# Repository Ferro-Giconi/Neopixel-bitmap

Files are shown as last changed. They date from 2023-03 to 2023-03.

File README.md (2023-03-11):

# Neopixel-bitmap
A Raspberry Pi Pico program to display images on a Neopixel RGB LED array.

Instructions:

1. Use BitmapToArray.py on your computer to convert bitmaps into arrays. Save those arrays to BitmapData.py following or replacing the existing examples.

2. Make sure your Pico/2040 device has MicroPython on it.

3. Add custom code for animations to the animations section in main.py

4. Make sure to set number_of_animations to the number of animations so it knows how many to loop through when pushing the buttons

5. Flash main.py and BitmapData.py to your RPi Pico/2040 device.

(Images or schematics or something to show how to connect all the hardware together will come later)

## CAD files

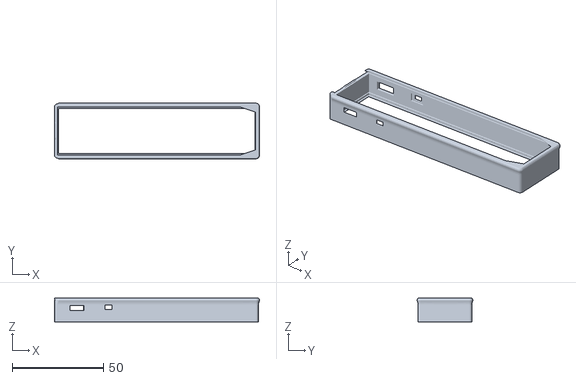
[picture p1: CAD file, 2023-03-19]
STL/main body with front insert.stl
112.4 x 30.5 x 13.1

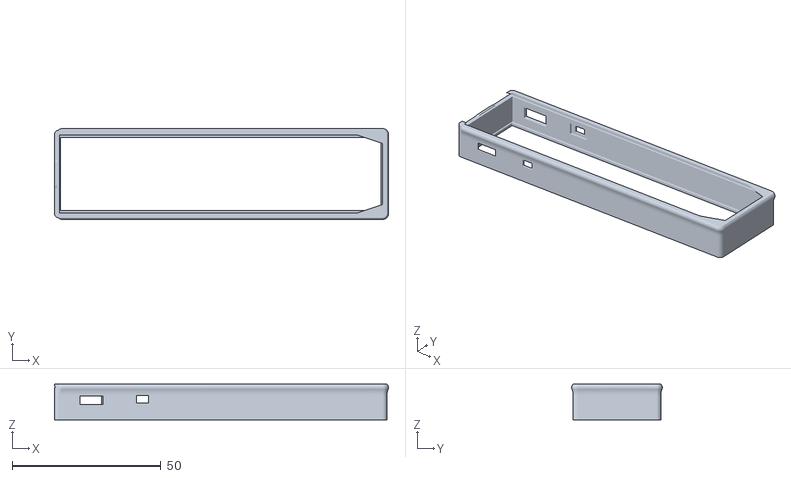
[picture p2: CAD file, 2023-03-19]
STL/main body with no front.stl
112.4 x 30.5 x 12.1

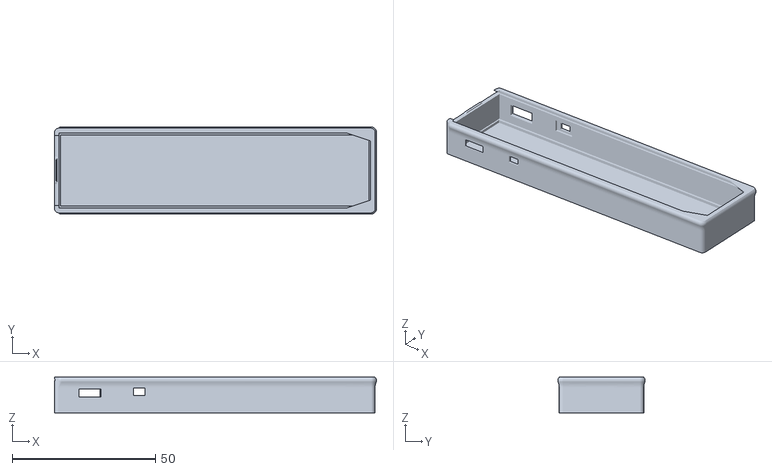
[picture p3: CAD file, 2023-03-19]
STL/main body with integrated front.stl
112.4 x 30.5 x 12.5

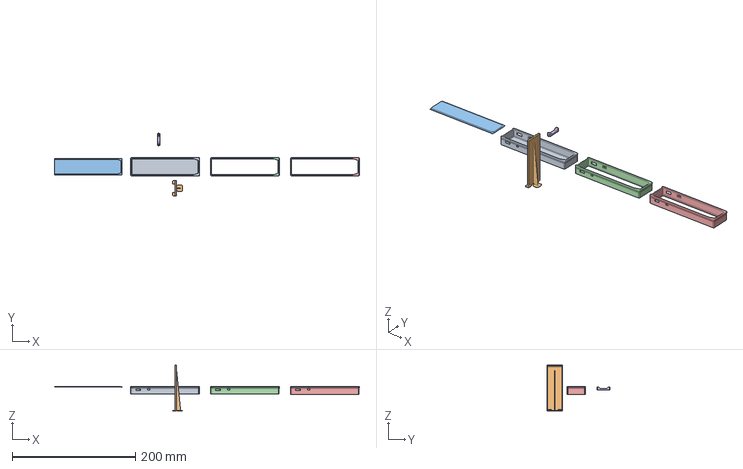
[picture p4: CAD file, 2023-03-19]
STL/All parts.step
495.9 x 102.6 x 74.7 mm

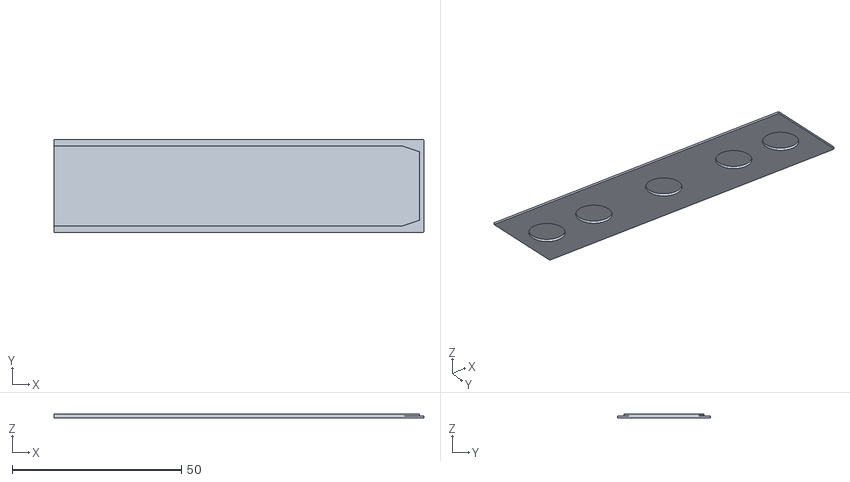
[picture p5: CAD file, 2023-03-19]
STL/back.stl
109.4 x 27.4 x 1.20

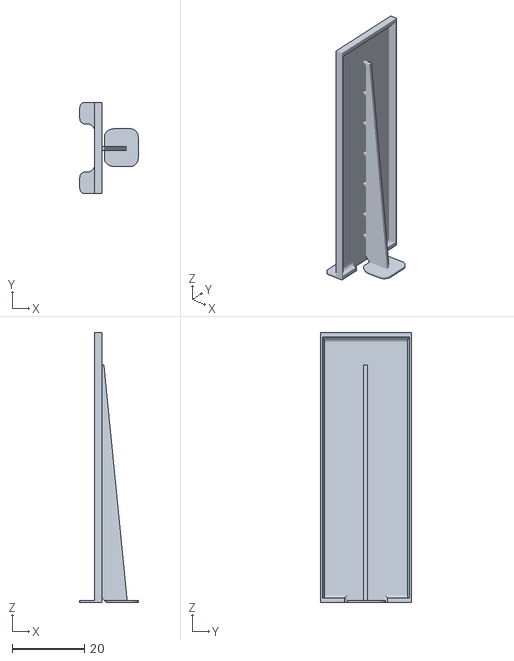
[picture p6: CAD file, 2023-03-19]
STL/battery tray.stl
16.2 x 25.3 x 74.7

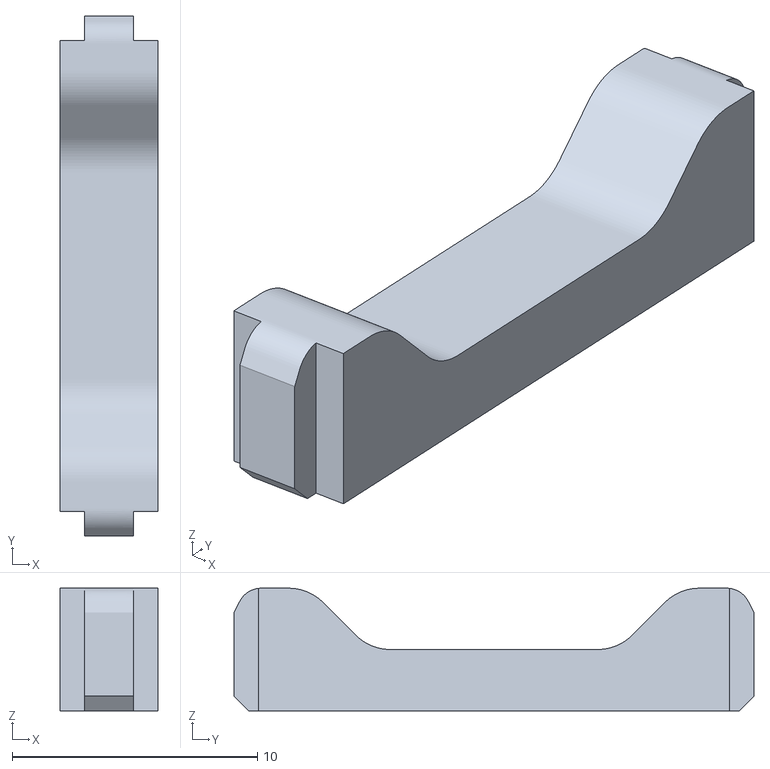
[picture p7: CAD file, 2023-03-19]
STL/button brace.stl
4.00 x 21.2 x 5.00

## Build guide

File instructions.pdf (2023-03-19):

# Required parts page 1

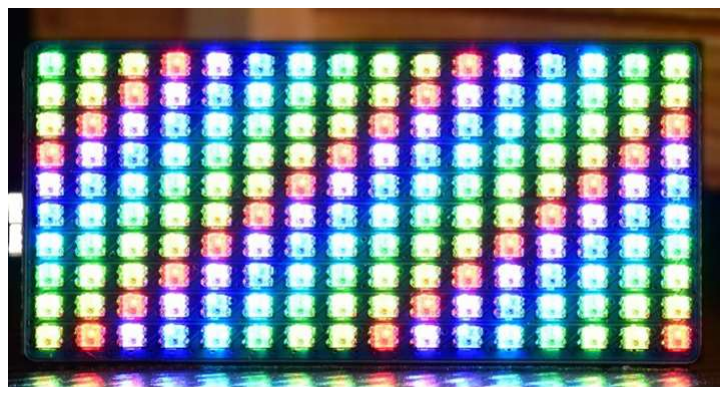
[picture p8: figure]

2 X Waveshare RGB Full-color LED Matrix Panel for Raspberry Pi Pico, 16×10 Grid
https://www.waveshare.com/pico-rgb-led.htmhttps://www.amazon.com/dp/B09CHFXLHV

### 1 X Pimironi Tiny 2040 8MB WITHOUT HEADER PINS

https://shop.pimoroni.com/products/tiny-2040?variant=39560012234835

### 1 X Pimironi LiPo SHIM for Pico

https://shop.pimoroni.com/products/pico-lipo-shim?variant=32369543086163

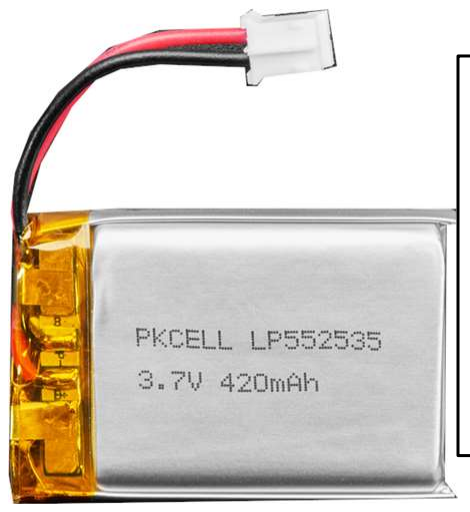
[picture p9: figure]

### 2 X LiPo battery 552535

https://www.adafruit.com/product/4236

(this was the best way I found to fit as much battery as possible into the space available. A single battery that fits the space would have been ideal to increase the mAh capacity but oh well.)

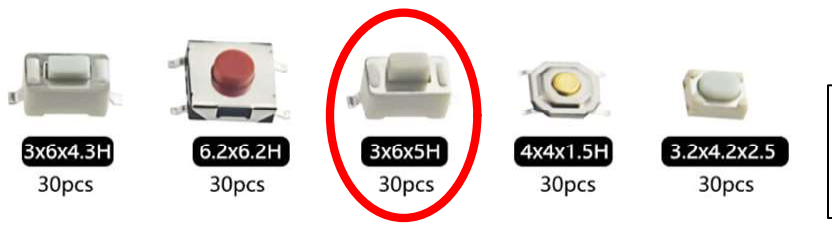
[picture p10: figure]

### 2 X 3x6x5H tactile switch

https://www.amazon.com/dp/B07GNZM4YJ

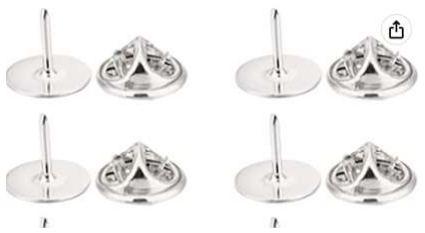
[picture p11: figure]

Pin backs, at least a 2 pack. Metal backings recommended, as the plastic ones can sometimes fall off. https://www.amazon.com/dp/B09WQHPBZW/

# Required parts page 2

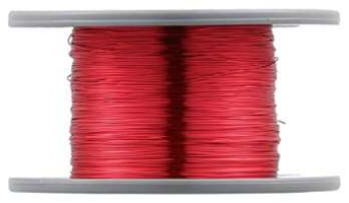
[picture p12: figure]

### 26 AWG enameled copper wire to carry up to 1A which can happen

with two Waveshare 16x10 arrays displaying all white.

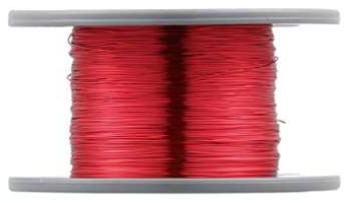
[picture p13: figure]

### 30 AWG enameled copper wire (optional)

To save space by using thinner wire on any wires that don’t need to carry current to and from the 16x10 LED arrays.

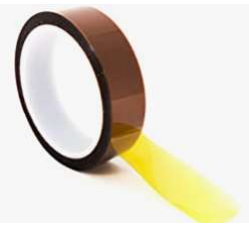
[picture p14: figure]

Polyimide Film with Silicone Adhesive. Also known as the name brand Kapton tape. This is needed to insulate stuff because there isn’t space for the thickness of normal electrical tape. I used 0.5" wide, but any width will work.

Other tools you will need: Soldering iron
Hot glue gun
Craft “xacto” knife.
3D printer

PicoShim: Remove the battery header.
Desolder all remaining metal bits. | Tiny 2040: Remove the buttons
| (The LED can stay)

Batteries: Remove the plug (but not the wires) from both batteries. Strip the ends of the wires, leaving about 1/8th of an inch of exposed wire. Put tape over the positive or negative so you don’t accidentally short something.

Required steps before assembly (but after testing on a breadboard)

Waveshare 16x10 LED array: Remove all three headers from the LED arrays.

Tip: use side cutters or another small cutting tool to break away the plastic. Once all the plastic is removed, it will be easier to desolder the remaining bits of metal.

Tip: use side cutters or another small cutting tool to break away the plastic. Once you get the switches to be as thin as the LED, you do not need to continue any further but if you do, be very careful when desoldering the buttons as it is very easy to rip off solder pads.

Tips:
Large headers: Wiggle back and forth gently a lot of times. They will eventually break off from metal fatigue. Desolder the individual pins now that they aren’t held together with a piece of plastic.

Small header: heat up the 5V pin solder first. Once it is melted, use side cutters to cut the plastic to remove the 5V pin. Do the same for the rest of the pins.

# Explanation of solder points

Tiny 2040: No special notes. PicoShim: Charge and Discharge should be bridged together.

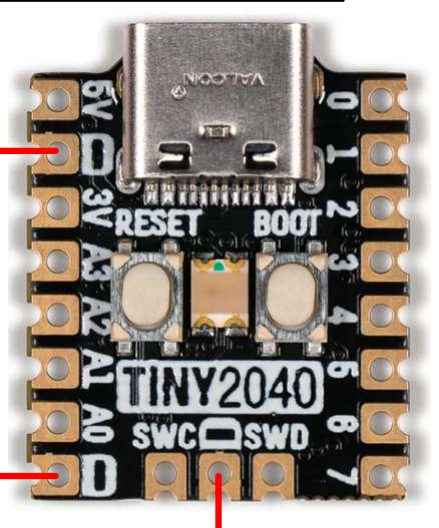
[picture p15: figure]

Charge

Discharge

Ground

Ground

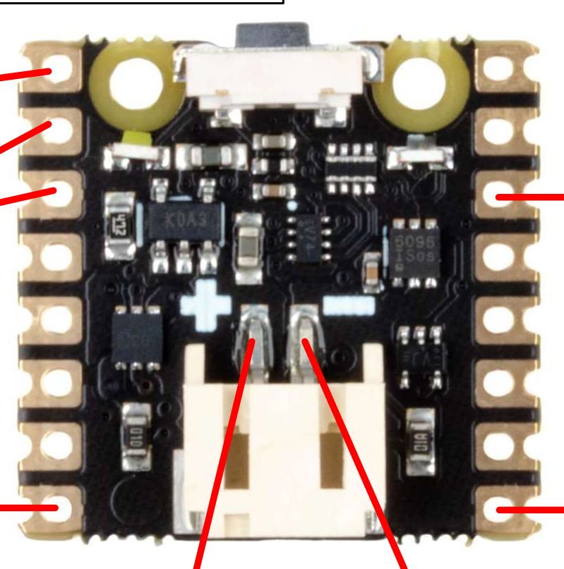
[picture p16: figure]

BAT + | BAT -

Waveshare 16x10 LED array: VBUS and 5V are the same. GP6 can be used as an alternative to DIN.

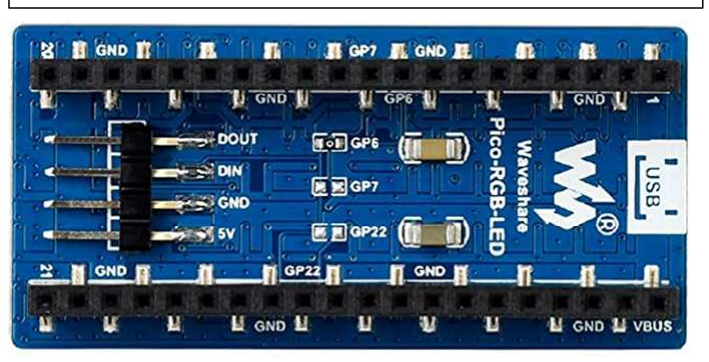
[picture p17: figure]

# Schematic

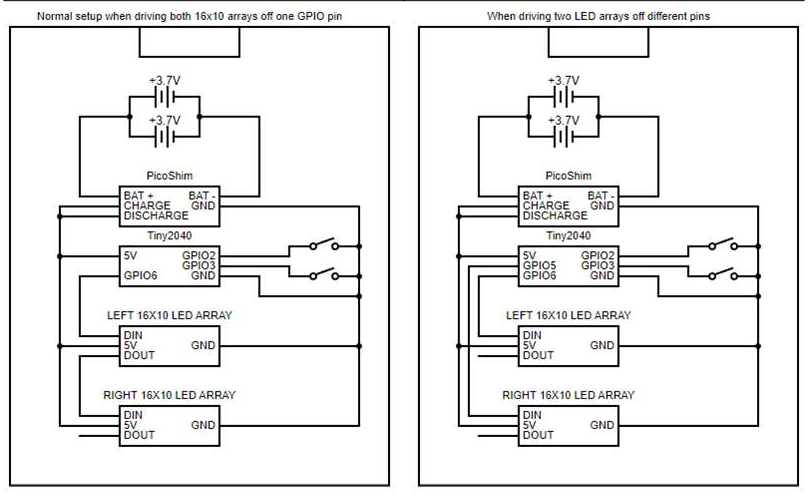
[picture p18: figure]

https://crcit.net/c/523c296d15b04a64b24df0ce39a208a0

Set the variable ImUsingPins6and5 = False Allows using any number of LED arrays

Set the variable ImUsingPins6and5 = True Only works with two LED arrays

# 3D printed parts page 1

Optimal 3D printer settings: Perimeter type: Arachne
Layer height: 0.2mm
Nozzle diameter: 0.4mm
Supports: Disabled
Infill: 100%
Print orientation: All files come in the correct print orientation.

Parts you will need to print:
1X of any “main body”.
1X back
1X battery tray
1X button brace

Instructions still in progress

# 3D printed parts page 2

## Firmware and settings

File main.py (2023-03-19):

# Waveshare 160 Neopixel Board Basic
# Tony Goodhew 19th April 2022 for thepihut.com
import array
import utime
from machine import Pin
import rp2
import random
import math
import micropython
import _thread


# ==================================== screen stuff ===================================
# in variable names: w = width on the x axis and h = height on the y axis

# define how many Neopixels you have, width and height
# when connecting multiple Neopixels, arrange them in order from left to right, then top to bottom.
global screens_w
screens_w = 2
global screens_h
screens_h = 1
# if there is a gap between Neopixels, define the gap size in number of LEDs.
# this will take gaps into account when displaying images or text for a more normal look.
# gap_w = gap width in number of pixels between horizontally places Neopixels
# gap_h = gap height in number of pixels between vertically stacked Neopixels
# Integer only. Decimals will probably break it.
global gap_w
gap_w = 0
global gap_h
gap_h = 0

# If you are using two NeoPixels on pins 5 and 6 to improve performance when using exactly 2 neopixels,
# set this to True. Otherwise, set it to False. This is an optimization specific to using two neopixels
# on those pins.
ImUsingPins6and5 = True

# I couldn't figure out how to check if the second thread is locked correctly so instead I'm using a global variable
global threadLocked
threadLocked = False

# Configure the number of WS2812 LEDs.
PIN_NUM = 6
brightness = 0.1


if screens_w == 2 and screens_h == 1 and gap_w == 0 and gap_h == 0:
    # use better optimized code if the layout is 2 screens wide with no gap.
    # this will let my 2x1 namebadge run a little faster without getting rid of
    # the code to use any number of neopixels.
    screen_total_width = 32
    screen_total_height = 10
    NUM_LEDS = 320
elif screens_w == 1 and screens_h == 1 and gap_w == 0 and gap_h == 0:
    # use better optimized code if the layout is 1 screen.
    screen_total_width = 16
    screen_total_height = 10
    NUM_LEDS = 160
else:
    # use slower code for any other configuration
    # set total number of LEDs. Each neopixel has 160 LEDs, 10H 16W.
    screen_total_width = screens_w * 16 + (screens_w * gap_w - gap_w)
    screen_total_height = screens_h * 10 + (screens_h * gap_h - gap_h)
    NUM_LEDS = screen_total_width * screen_total_height

    #calculates which X and Y cordinates will not be used if there are gaps defined
    global missing_x
    missing_x = []
    for i in range(16,screen_total_width+1,1):
        ii = i
        while ii > 16:
            ii = ii - 16 - gap_w
        if ii <= 0:
            missing_x.append(i)

    global missing_y
    missing_y = []
    for i in range(10,screen_total_height+1,1):
        ii = i
        while ii > 10:
            ii = ii - 10 - gap_h
        if ii <= 0:
            missing_y.append(i)

# Boilerplate Neopixel driver for RP2040
@rp2.asm_pio(sideset_init=rp2.PIO.OUT_LOW, out_shiftdir=rp2.PIO.SHIFT_LEFT, autopull=True, pull_thresh=24)
def ws2812():
    T1 = 2
    T2 = 5
    T3 = 3
    wrap_target()
    label("bitloop")
    out(x, 1)               .side(0)    [T3 - 1]
    jmp(not_x, "do_zero")   .side(1)    [T1 - 1]
    jmp("bitloop")          .side(1)    [T2 - 1]
    label("do_zero")
    nop()                   .side(0)    [T2 - 1]
    wrap()

if ImUsingPins6and5:
    sm1 = rp2.StateMachine(0, ws2812, freq=8_000_000, sideset_base=Pin(6))
    sm2 = rp2.StateMachine(1, ws2812, freq=8_000_000, sideset_base=Pin(5))
    sm1.active(1)
    sm2.active(1)
    ar = array.array("I", [0 for _ in range(320)])
    ar2 = array.array("I", [0 for _ in range(160)])
    ar3 = array.array("I", [0 for _ in range(160)])
else:
    # Create the StateMachine with the ws2812 program, outputting on pin
    # You can also increase the frequency to improve performance by 1-2ms
    sm = rp2.StateMachine(0, ws2812, freq=8_000_000, sideset_base=Pin(PIN_NUM))

    # Start the StateMachine, it will wait for data on its FIFO.
    sm.active(1)

    # Display a pattern on the LEDs via an array of LED RGB values.
    ar = array.array("I", [0 for _ in range(NUM_LEDS)])

####################### Functions ##############################
if ImUsingPins6and5:
    def pixels_show():
        while threadLocked:
            utime.sleep_ms(1)
        # This 2ms sleep prevents a race condition.
        utime.sleep_ms(2)
        ar2 = ar[:len(ar)//2]
        global ar3
        ar3 = ar[len(ar)//2:]
        _thread.start_new_thread(pixels_show_thread2,())
        dimmer_ar = array.array("I", [0 for _ in range(160)])
        # TimeCounter3 = utime.ticks_ms()
        for i,c in enumerate(ar2):
            r = int(((c >> 8) & 0xFF) * brightness)
            g = int(((c >> 16) & 0xFF) * brightness)
            b = int((c & 0xFF) * brightness)
            dimmer_ar[i] = (g<<16) + (r<<8) + b
        # print('1 took ' + str(utime.ticks_ms()-TimeCounter3) + ' ms')
        sm1.put(dimmer_ar, 8)
        while threadLocked:
            utime.sleep_ms(1)

    def pixels_show_thread2():
        global threadLocked
        threadLocked = True
        dimmer_ar = array.array("I", [0 for _ in range(160)])
        for i,c in enumerate(ar3):
            r = int(((c >> 8) & 0xFF) * brightness)
            g = int(((c >> 16) & 0xFF) * brightness)
            b = int((c & 0xFF) * brightness)
            dimmer_ar[i] = (g<<16) + (r<<8) + b
        sm2.put(dimmer_ar, 8)
        threadLocked = False
else:
    def pixels_show():
        dimmer_ar = array.array("I", [0 for _ in range(NUM_LEDS)])
        for i,c in enumerate(ar):
            r = int(((c >> 8) & 0xFF) * brightness)
            g = int(((c >> 16) & 0xFF) * brightness)
            b = int((c & 0xFF) * brightness)
            dimmer_ar[i] = (g<<16) + (r<<8) + b
        sm.put(dimmer_ar, 8)

def pixels_set(i, colour):
    ar[i] = (colour[1]<<16) + (colour[0]<<8) + colour[2]

def pixels_fill(colour):
    _thread.start_new_thread(pixels_fill_thread2,((colour),))
    for i in range(math.ceil(len(ar)/2)):
        pixels_set(i, colour)
    # wait for the second thread to finish before continuing
    while threadLocked:
        utime.sleep_ms(1)

def pixels_fill_thread2(colour):
    global threadLocked
    threadLocked = True
    for i in range(math.ceil(len(ar)/2),len(ar)):
        pixels_set(i, colour)
    threadLocked = False
    _thread.exit()

def clear():
    colour = (0,0,0)
    pixels_fill(colour)

def xy_set(x, y, colour):
    #check if a pixel is valid and set it if it is
    if valid_pixel(x,y):
        xy_set_valid(x, y, colour)

if screens_w == 2 and screens_h == 1 and gap_w == 0 and gap_h == 0:
    # use better optimized code if the layout is 2 screens wide with no gap.
    # this will let my 2x1 namebadge run a little faster without getting rid of
    # the code to use any number of neopixels.
    def xy_set_valid(x, y, colour):
        # Sets a pixel. This causes errors if you try to set a pixel that doesn't exist.
        # You should use xy_set() instead if you want to set a single pixel.
        if x > 15:
            screen_number = 1
            x = x - 16
        else:
            screen_number = 0
        #calculate which pixel to set on which Neopixel
        pos = (screen_number * 160) + x + y * 16
        pixels_set(pos, colour)

    def valid_pixel(x,y):
        # check if a pixel is valid
        if (x<0) or (y<0) or (x > 31) or (y > 9):
            valid_pixel = False
        else:
            valid_pixel = True
        return valid_pixel
elif screens_w == 1 and screens_h == 1 and gap_w == 0 and gap_h == 0:
    # use even better optimized code if using only one neopixel
    def xy_set_valid(x, y, colour):
        pos = x + y * 16
        pixels_set(pos, colour)
    def valid_pixel(x,y):
        if (x<0) or (y<0) or (x > 15) or (y > 9):
            valid_pixel = False
        else:
            valid_pixel = True
        return valid_pixel
else:
    # Use less optimized bode, but code that supports any layout you could possibly want.
    def xy_set_valid(x, y, colour):
        # +1 to x and y allows me to do pixel math in this function starting at 1 when the input x and y start at 0.
        # it's just easier for me to figure out the math that way.
        x = x + 1
        y = y + 1
        screen_x = 1
        screen_y = 1
        xx = x
        yy = y
        while xx > 16:
            screen_x = screen_x + 1
            xx = xx - 16 - gap_w
        while yy > 10:
            screen_y = screen_y + 1
            yy = yy - 10 - gap_h
        screen_number = screen_x + ((screen_y - 1) * screens_w)
        #calculate which pixel to set on which Neopixel
        pos = ((screen_number - 1) * 160) + (xx - 1) + (yy - 1) * 16
        pixels_set(pos, colour)
    # it seems silly to do this but anything that can save an operation two in the valid pixel check will
    # help improve how many μs each frame takes to display
    global screen_total_width_minus_one
    screen_total_width_minus_one = screen_total_width - 1
    global screen_total_height_minus_one
    screen_total_height_minus_one = screen_total_height - 1
    def valid_pixel(x,y):
        valid_pixel = True
        # Check if the pixel you want to set is outside the size of the
        # screen to avoid wasting CPU cycles on pixels that you can't see
        if (x<0) or (y<0) or (x > screen_total_width - 1) or (y > screen_total_height - 1):
            valid_pixel = False
        # If you configured a gap between neopixels, check if the pixel is on a gap
        if valid_pixel:
            for i in missing_x:
                if x == i:
                    valid_pixel = False
            for i in missing_y:
                if y == i:
                    valid_pixel = False
        return valid_pixel

def rect(x,y,w,h,r,g,b):
    # Hollow square at (x,y), w pixels wide coloured (r,g,b)
    _thread.start_new_thread(rect_threads,(x,y,w,h,r,g,b,1))
    rect_threads(x,y,w,h,r,g,b,0)
    while threadLocked:
        utime.sleep_ms(1)

def rect_threads(x,y,w,h,r,g,b,threadNum):
    if threadNum:
        global threadLocked
        threadLocked = True
        cc = (r,g,b)
        for i in range(x,x+w):
            if valid_pixel(i,y):
                xy_set_valid(i,y,cc)       # Top
            if valid_pixel(i,y+h-1):
                xy_set_valid(i,y+h-1,cc)   # Bottom
    else:
        cc = (r,g,b)
        for i in range(y+1,y+h):
            if valid_pixel(x,i):
                xy_set_valid(x,i,cc)       # Left
            if valid_pixel(x+w-1,i):
                xy_set_valid(x+w-1,i,cc)   # Right
    if threadNum:
        threadLocked = False

def vert(x,y,l,r,g,b):
    # Vertical line at (x,y) of length l coloured (r,g,b)
    cc = (r,g,b)
    for i in range(l):
        if valid_pixel(x,i):
            xy_set_valid(x,i,cc)

def horiz(x,y,l,r,g,b):
    # Horizontal line from (x,y) of length l coloured (r,g,b)
    cc = (r,g,b)
    for i in range(l):
        if valid_pixel(i+x,y):
            xy_set_valid(i+x,y,cc)

def bitmap_set_fast(x,y,w,h,r,g,b):
    # bitmap_set(x_coordinate, y_coordinate, bmp_width, bmp_height, bmp_red, bmp_green, bmp_blue)
    # set the pixels for a bitmap. No gama, brightness, or transparency modifications.
    # start at pixel zero
    PxNum = 0
    for i in range(h):
        for j in range(w):
            if valid_pixel(j+x,i+y):
                # use the heavily modified xy_set to set each pixel
                xy_set_valid(j+x,i+y,(r[PxNum],g[PxNum],b[PxNum]))
            PxNum = PxNum + 1

def bitmap_set24(x,y,ia,ga=1,br=1,tr=False):
    # bitmap_set(x_coord, y_coord, image_array, gama, brightness, transparency)
    # use for placing a 24 bit bitmap somewhere on screen.
    
    # start a thread to process the lower half of the pixels
    _thread.start_new_thread(bitmap_set24_threads,(x,y,ia,ga,br,tr,1))
    # start a the function to run at the same time as the thread to process the upper half of the pixels
    bitmap_set24_threads(x,y,ia,ga,br,tr,0)
    # wait for the thread to finish if it isn't done yet
    while threadLocked:
        utime.sleep_ms(1)

def bitmap_set24_threads(x,y,ia,ga,br,tr,threadNum):
    # do not call this function directly. This is used by bitmap_set24 to run my innefficient code on
    # two cores at once to improve performance
    w = ia[0][0]
    h = ia[1][0]
    r = ia[2]
    g = ia[3]
    b = ia[4]
    if threadNum:
        global threadLocked
        threadLocked = True
        PxNum = w*math.ceil(h/2)
        range1 = math.ceil(h/2)
        range2 = h
    else:
        PxNum = 0
        range1 = 0
        range2 = math.ceil(h/2)
    for i in range(range1,range2,1):
        for j in range(w):
            if valid_pixel(j+x,i+y):
            # if transparency is disabled, or if it is enabled and the r,g,b isn't 0,0,0, draw the pixel.
                if tr and (r[PxNum]+g[PxNum]+b[PxNum] > 0) or (not tr):
                    # compress the data range from 0-255 to 0-246 to compensate for the 0-9 pixels all being black
                    rr = r[PxNum]*246/255
                    gg = g[PxNum]*246/255
                    bb = b[PxNum]*246/255
                    # adjust the brightness
                    rr = rr*br
                    gg = gg*br
                    bb = bb*br
                    # This is a crude gama adjustment formula which can help make bitmaps look more normal instead of washed out
                    rr = math.pow(rr,ga) * 246 / math.pow(246,ga)
                    gg = math.pow(gg,ga) * 246 / math.pow(246,ga)
                    bb = math.pow(bb,ga) * 246 / math.pow(246,ga)
                    # undo the compression
                    rr = math.ceil(rr+9)
                    gg = math.ceil(gg+9)
                    bb = math.ceil(bb+9)
                    # use the heavily modified xy_set to set each pixel
                    xy_set_valid(j+x,i+y,(rr,gg,bb))
            PxNum = PxNum + 1
    if threadNum == 1:
        threadLocked = False
        _thread.exit()

def bitmap_set1(x,y,ia,r,g,b,tr=False):
    # bitmap_set(x_coord, y_coord, image_array,color,transparency)
    # Sets a 1 bit bitmap using a defined color
    # start a thread to process the lower half of the pixels

    _thread.start_new_thread(bitmap_set1_threads,(x,y,ia,r,g,b,tr,1))
    # start a the function to run at the same time as the thread to process the upper half of the pixels
    bitmap_set1_threads(x,y,ia,r,g,b,tr,0)
    # wait for the thread to finish if it isn't done yet
    while threadLocked:
        utime.sleep_ms(1)

            
def bitmap_set1_threads(x,y,ia,r,g,b,tr,threadNum):
    # bitmap_set(x_coord, y_coord, image_array,color,transparency)
    # Sets a 1 bit bitmap using a defined color
    w = ia[0][0]
    h = ia[1][0]
    p = ia[2]
    if threadNum:
        global threadLocked
        threadLocked = True
        PxNum = w*math.ceil(h/2)
        range1 = math.ceil(h/2)
        range2 = h
    else:
        PxNum = 0
        range1 = 0
        range2 = math.ceil(h/2)
    for i in range(range1,range2,1):
        for j in range(w):
            if valid_pixel(j+x,i+y):
                if tr and p[PxNum] or not tr and j < 33:
                    xy_set_valid(j+x,i+y,(p[PxNum]*r,p[PxNum]*g,p[PxNum]*b))
            PxNum = PxNum + 1
    if threadNum:
        threadLocked = False

# ======================= BUTTON HANDLING ========================
button2 = Pin(2, Pin.IN, Pin.PULL_UP)
button3 = Pin(3, Pin.IN, Pin.PULL_UP)

button_presses = 0 # the count of times the button has been pressed
button_presses_last = 0
button_last_time = 0 # the last time we pressed the button

# This function gets called every time the button is pressed.
def button_pressed(pin):
    global button_presses, button_last_time
    button_new_time = utime.ticks_ms()
    
    # check the time for simple debouncing to prevent the button from triggering like 20 times when pressed
    if (button_new_time - button_last_time) > 200:
        # this should be pin.id but it does not work
        if '3' in str(pin):
            button_presses +=1
        elif '2' in str(pin):
            button_presses -=1
        button_last_time = button_new_time
        print(str(pin))

def buttonBreak():
    # simple function to make code more readable in the animations
    global button_presses, button_presses_last
    if not button_presses == button_presses_last:
        return True

button2.irq(trigger=Pin.IRQ_FALLING, handler = button_pressed)
button3.irq(trigger=Pin.IRQ_FALLING, handler = button_pressed)



# ========= Random information ========
micropython.mem_info()
TimeCounter = utime.ticks_ms()
print(utime.ticks_ms()-TimeCounter)

# ========= Define animation code here as functions ========
# animations that you want to be interrupted by buttons should have the one line
# if buttonBreak():break
# in the animation's loops to make sure the animation can be stopped in a timely manner

import BitmapData

def animation0():
    # blank animation so it doesn't light up super bright when plugged into usb for charging
    clear()
    while True:
        xy_set(1,1,(10,0,10))
        pixels_show()
        utime.sleep_ms(200)
        xy_set(1,1,(0,0,0))
        pixels_show()
        utime.sleep_ms(50)
        if buttonBreak():break

def animation1():
    # Displays the text "load..." which I created thinking there might be a perceptible loading time
    # but there wasn't so it's just one of the example animations.
    for i in range(17,-17,-1):
        clear()
        bitmap_set1(i,2,BitmapData.bitmap(2),40,0,40,False)
        pixels_show()
        # break the for loop if a buttnon is pressed so animation changes are more responsive
        if buttonBreak():break

def animation2():    
    # displays a rainbow gradient using a tiled bitmap
    bg_pos = -12
    for i in range(12):
        # draw the background which is a tiled 12 pixel image
        for j in range(3):
            bitmap_set24(j*12+bg_pos,2,BitmapData.bitmap(4),1.8,.3)
        bg_pos = bg_pos + 1
        if bg_pos == 0:
            bg_pos = -12
        pixels_show()
        if buttonBreak():break

def animation3():
    # fancy scrolling text example with utime.sleep used to make frame times consistent
    # "JAYDE THE GOO DEER" in rainbow
    for sadfjhasd in range(1):
        bg_pos = -11
        for i in range(32,-82,-1):
            FrameTime = utime.ticks_ms()
            # draw the background which is a tiled 12 pixel image
            for j in range(4):
                bitmap_set24(j*12+math.floor(bg_pos),2,BitmapData.bitmap(4),1,1)
            bg_pos = bg_pos + .5
            if bg_pos == 0:
                bg_pos = -11
            # draw the text.
            bitmap_set1(i,2,BitmapData.bitmap(3),0,0,0,True)
            # draw black pixels to prevent the background from being visible once the text passes
            if i > 0:
                for j in range(2,8,1):
                    horiz(0,j,i,0,0,0)
            if i < 32-81:
                for j in range(2,8,1):
                    horiz(i+81,j,32-i-81,0,0,0)
            utime.sleep_ms(100 - (utime.ticks_ms() - FrameTime))
            pixels_show()
            if buttonBreak():break

def animation4():
    # asparagus animation
    for i in range(34,-81,-1):
        FrameTime = utime.ticks_ms()
        clear()
        bitmap_set24(i,0,BitmapData.bitmap(5),3.1,.8)
        utime.sleep_ms(100 - (utime.ticks_ms() - FrameTime))
        pixels_show()
        if buttonBreak():break
    

# ======================= Runs animations on a loop ==================

# set how any animations to loop through with buttons
number_of_animations = 4
while True:
    if not button_presses_last == button_presses:
        # only clear the screen if the animation is changed, otherwise let the
        # animation handle its own screen clearing
        clear()
        button_presses_last = button_presses
    
    if button_presses < 0:
        button_presses = number_of_animations
    if button_presses > number_of_animations:
        button_presses = 0
        
    # play the selected animation
    TimeCounter = utime.ticks_ms()
    eval('animation' + str(button_presses) + '()')
    print('Animation ' + str(button_presses) + ' took ' + str(utime.ticks_ms()-TimeCounter) + 'ms')
    
    
    

clear()
pixels_show()

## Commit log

2023-02-20 Update and rename PicoBitmap.py to NeopixelBitmap.py
    Renamed the file and modified some of the bitmap handling code so 1 bit and 24 bit bitmaps are handled in a more similar way. Changed the examples. Added multithreading to the 1 bit bitmaps. The curr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
2023-02-21 imperceptibly tiny performance improvement
    I tried a silly little optimization in function valid_pixel() to improve performance slightly. It saved 280 μs per frame averaged across all the examples. Which is almost nothing, but it's still more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
2023-02-25 Added buttons
    - added button functionality with pins 4 and 5 to cycle through animations.
    - moved animations to each be in their own function to then be called by a while true loop that checks the current animation number and plays it.
2023-03-09 Added battery voltage
    - Added code to read the battery voltage. It is not implemented on the display yet but I intend on displaying the voltage for a second or so every time it is powered on. Currently it is only a print(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
    - Other very minor changes from messing with animation code
2023-03-11 Update and rename NeopixelBitmap.py to main.py
    Changed NeopixelBitmap.py to main.py because that's the name used on the RPi Pico.
    removed unused function ButtonHandler()
    Changed the buttons to pin 2 and 3 because those were a bit easier to access when soldering parts in an enclosure.
    Removed the voltage/battery percentage code because it was inconsistent and I didn't want to have to add the resistors for the voltage divider to the enclosure.
    Moved bitmap data to a separate file to make the code a little less cumbersome to work on.
    [main.py]
2023-03-19 Update main.py
    - Added a dim flashing dot animation so it doesn't flashbang me every time I plug it in. This thing goes really bright.
    - Changed animation 4 to use the asparagus bitmap
    - Added optimized code for 2x1 and 1x1 layouts so it does less math on every pixel if it is a 1x1 or 2x1 layout without gaps.
    Results of optimization on 2x1:
    Asparagus animation before optimization with frame time consistency removed for maximum scroll speed:
    12762 MS
    Asparagus animation after optimization:
    12196 MS (4.4% improvement)
    - Removed adjust_gama_list() and adjust_gama() as they aren't used and need to be implemented differently if they are going to be used.
    [main.py]
2023-03-19 optimizations for 2x1
    - Further optimization when using this in a 2x1 setup by creating special multi-threading that only works if you wire each neopixel up to it's own GPIO pin.
    Asparagus animation after previous recent optimization:
    Asparagus animation after adding multi-threading and putting each neopixel on it's own pin:
    10360 MS (18.8% improvement)
    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
2023-03-19 Update BitmapToArray.py
    Fixed so it output bitmaps in the correct format for changes to how bitmaps are read.
    [BitmapToArray.py]
